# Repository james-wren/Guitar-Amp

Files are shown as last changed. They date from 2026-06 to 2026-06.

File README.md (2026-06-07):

# Guitar-Amp
## Description
A 4 inch and electric guitar amplifier using the LM386n-4 and J201 JFETS. Operates using 4 main stages:
1. JFET input boost, the signal coming from a guitar is very weak, so it needs to be boosted to a usable level
2. Tone control, uses a 50k POT to control the guitars tone, this stage decreases the signal strength
3. JFET tone boost, boosts the signal strength back up to usable level.
4. Audio amplification, uses the LM386n-4 to amplify the audio to ~1w, ideal for a 4 inch speaker



The board is designed to use only THT components to save money as it can ban easily soldered with basic tools, to aid in the easy assembly parts are also spread out over a almost 200mm width. Components start on the left with the 1/4 inch jack input, wrap around the top, and end on the right with the speaker output. It is mounted to the case using m2 screws.




The case is pretty simple, just a speaker on the front with the three potentiometers and input jack up top, the 12v barrel is located on the back of the case near the bottom, the case is printed in two parts, the back plate is printed seperatly and screwed on with two M2 screws.

  

Inside mounting holes of back plate:  



## Instructions
### Build 
1. Solder components onto the pcb, simply solder the through hole components, no special gear is needed.
2. Wire potentiometers, the input jack, 12v barrel, and the speaker. Solder using 22AWG wire to thier respective pads
3. Print case in any orientation prefered, note that supports will be needed for the main body.
4. Screw in components, the pcb and backplate use m2 screws, and the speaker uses m8.

### Usage
1. Plug in guitar, reccomend starting with this to avoid a loud, high piched noise.
2. Plug in 12v barrel to turn on amp
3. Adjust knobs to prefered tune
4. Play your guitar!

## Why I made this
Pretty simple, I don't have an AMP, but I do have a guitar (I actually built it myself). After building I decieded that I wanted to learn to play, until this I had been plugging it into my old ipod and using garage band as an amp, but this was pretty terrible so I decieded this would be a fun first hardware project

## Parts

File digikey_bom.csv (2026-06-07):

Country of Origin may be different at time of shipment.
The HTSUS and ECCN information shown is for informational purposes only and is not a representation or warranty as to the accuracy or reliability of these classifications. All information is provided "as is" and is subject to change without notice. Any use made of the information provided is without recourse to Digi-Key and at the user's risk.
Index | Manufacturer Part Number | Manufacturer Name | Description | Lead Time | Availability | Stock Status | Attrition % | Requested Quantity 1 | Pack Quantity 1 | Pack Type 1 | Digi-Key Part Number 1 | Unit Price 1 | Extended Price 1 | Minimum Order Quantity 1 | Customer Reference | Requested Part Number | Lead Weeks | Datasheet | Reference Designator | US Import Tariff | Note | Part Status | RoHS Status | REACH Status | Moisture Sensitivity Level (MSL) | ECCN | HTSUS | Country of Origin | Environmental Information | Original Part numbers | Unit of Measure | Image | Product Notes
1 | C315C682K5R5TA | KEMET | CAP CER 6800PF 50V X7R RADIAL |  | 7,642 | In Stock |  | 1 | 1 | Bulk | 399-4194-ND | 0.34000 | $0.34 | 1 |  | 399-4194-ND | 26 | https://yageogroup.com/content/datasheet/asset/file/KEM_C1050_GOLDMAX_X7R |  | - |  | Active | ROHS3 Compliant | REACH Unaffected | Not Applicable | EAR99 | 8532.24.0060 | Mexico |  | 399-4194-ND | Each | https://mm.digikey.com/Volume0/opasdata/d220001/medias/images/2503/GOLDENMAX%20300%20C0G%2C%20NP0.jpg
2 | A103K15X7RF5TAA | Vishay Beyschlag/Draloric/BC Components | CAP CER 10000PF 50V X7R AXIAL |  | 145,753 | In Stock |  | 1 | 1 | Cut Tape (CT) | 1103PHCT-ND | 0.26000 | $0.26 | 1 |  | 1103PHCT-ND | 18 | https://www.vishay.com/docs/45164/aseries.pdf |  | May apply on shipments to the U.S. |  | Active | ROHS3 Compliant | REACH Unaffected | Not Applicable | EAR99 | 8532.24.0040 | China |  | 1103PHCT-ND | Each | https://mm.digikey.com/Volume0/opasdata/d220001/medias/images/591/A152K15X7RF5TAA.jpg
3 | FK20X7S1H106KR000 | TDK | CAP CER 10UF 50V X7S RADIAL |  | 143,250 | In Stock |  | 2 | 2 | Bulk | 445-FK20X7S1H106K-ND | 1.24000 | $2.48 | 1 |  | 445-FK20X7S1H106K-ND | 40 | https://product.tdk.com/en/system/files/dam/doc/product/capacitor/ceramic/lead-mlcc/catalog/leadmlcc_conventional_fk_en.pdf |  | May apply on shipments to the U.S. |  | Not For New Designs | ROHS3 Compliant | REACH Unaffected | Not Applicable | EAR99 | 8532.24.0060 | China | https://product.tdk.com/en/environment/index.html | 445-FK20X7S1H106K-ND | Each | https://mm.digikey.com/Volume0/opasdata/d220001/medias/images/631/FK54-SERIES.jpg
4 | C410C104Z5U5TA7200 | KEMET | CAP CER 0.1UF 50V Z5U AXIAL |  | 165,394 | In Stock |  | 1 | 1 | Cut Tape (CT) | 399-C410C104Z5U5TA7200CT-ND | 0.26000 | $0.26 | 1 |  | 399-C410C104Z5U5TA7200CT-ND | 30 | https://yageogroup.com/content/datasheet/asset/file/KEM_C1042_AXIMAX_Z5U |  | May apply on shipments to the U.S. |  | Active | ROHS3 Compliant | REACH Unaffected | Not Applicable | EAR99 | 8532.24.0040 | Mexico |  | 399-C410C104Z5U5TA7200CT-ND | Each | https://mm.digikey.com/Volume0/opasdata/d220001/medias/images/1278/MFG_C4x0Cxxxxxx5TAAUTO.jpg
5 | UHE1H221MPD | Nichicon | CAP ALUM 220UF 20% 50V RADIAL TH |  | 64,731 | In Stock |  | 1 | 1 | Bulk | 493-1609-ND | 0.65000 | $0.65 | 1 |  | 493-1609-ND | 21 | https://www.nichicon.co.jp/english/series_items/catalog_pdf/e-uhe.pdf |  | - |  | Active | ROHS3 Compliant | REACH Affected | Not Applicable | EAR99 | 8532.22.0020 | Malaysia |  | 493-1609-ND | Each | https://mm.digikey.com/Volume0/opasdata/d220001/medias/images/2894/HE%20SERIES%20PURPLE%2016.0%2C10.0.jpg
6 | 50NXA100MEFC10X16 | Rubycon | CAP ALUM 100UF 20% 50V RADIAL TH |  | 2,213 | In Stock |  | 1 | 1 | Bulk | 1189-50NXA100MEFC10X16-ND | 0.82000 | $0.82 | 1 |  | 1189-50NXA100MEFC10X16-ND | 22 | https://www.rubycon.co.jp/wp-content/uploads/catalog-aluminum/NXA.pdf |  | May apply on shipments to the U.S. |  | Active | ROHS3 Compliant | REACH Unaffected | Not Applicable | EAR99 | 8532.22.0020 | Japan |  | 1189-50NXA100MEFC10X16-ND | Each | https://mm.digikey.com/Volume0/opasdata/d220001/medias/images/913/NXA-Series.jpg
7 | ECE-A1HN471U | Panasonic Industry | CAP ALUM 470UF 20% 50V RADIAL TH |  | 32 | In Stock |  | 1 | 1 | Bulk | P1287-ND | 2.72000 | $2.72 | 1 |  | P1287-ND | 31 | https://industrial.panasonic.com/cdbs/www-data/pdf/RDF0000/ABA0000C1053.pdf |  | May apply on shipments to the U.S. |  | Active | ROHS3 Compliant | REACH Unaffected | Not Applicable | EAR99 | 8532.22.0020 | Malaysia |  | P1287-ND | Each | https://mm.digikey.com/Volume0/opasdata/d220001/derivates/6/001/120/017/ECE-A1HN471U_web%28640x640%29.jpg
8 | 1N5338BRLG | onsemi | DIODE ZENER 5.1V 5W AXIAL |  | 23,668 | In Stock |  | 2 | 2 | Cut Tape (CT) | 1N5338BRLGOSCT-ND | 0.80000 | $1.60 | 1 |  | 1N5338BRLGOSCT-ND | 19 | https://www.onsemi.com/pub/Collateral/1N5333B-D.PDF |  | May apply on shipments to the U.S. |  | Active | ROHS3 Compliant | REACH Unaffected | Not Applicable | EAR99 | 8541.10.0050 | China | https://www.onsemi.com/site/pdf/RoHS-statement.pdf|https://www.onsemi.com/PowerSolutions/MaterialComposition.do?export=pdf&opnId=1N5338BRLG | 1N5338BRLGOSCT-ND | Each | https://mm.digikey.com/Volume0/opasdata/d220001/medias/images/5023/488%7E017AA-01%7E%7E2.jpg
9 | 1N4007 | Diotec Semiconductor | DIODE STANDARD 1000V 1A DO204AC |  | 42,464 | In Stock |  | 1 | 1 | Cut Tape (CT) | 4878-1N4007CT-ND | 0.14000 | $0.14 | 1 |  | 4878-1N4007CT-ND | 6 | https://diotec.com/request/datasheet/1n4001.pdf |  | May apply on shipments to the U.S. |  | Active | ROHS3 Compliant | REACH Unaffected | Not Applicable | EAR99 | 8541.10.0080 | China | https://diotec.com/request/imds/p1_e.pdf | 4878-1N4007CT-ND | Each | https://mm.digikey.com/Volume0/opasdata/d220001/derivates/6/003/243/002/MFG_4878%7EDO41-DO204AC%7E%7E2_web%28640x640%29.jpg
10 | EJ501A | MPD (Memory Protection Devices) | CONN PWR JACK 2.1X5.5MM SOLDER |  | 4,305 | In Stock |  | 1 | 1 | Bulk | EJ501A-ND | 1.89000 | $1.89 | 1 |  | EJ501A-ND | 20 | https://www.memoryprotectiondevices.com/datasheets/EJ501A/EJ501A-datasheet.pdf |  | May apply on shipments to the U.S. |  | Active | RoHS Compliant | REACH Unaffected | 1 (Unlimited) | EAR99 | 8536.69.4010 | Taiwan |  | EJ501A-ND | Each | https://mm.digikey.com/Volume0/opasdata/d220001/medias/images/1123/MFG_EJ501A.jpg
11 | CSS-1021028N | Same Sky (Formerly CUI Devices) | SPEAKER 8OHM 10W TOP PORT 107DB |  | 5,132 | In Stock |  | 1 | 1 | Box | 102-3849-ND | 7.92000 | $7.92 | 1 |  | 102-3849-ND | 18 | https://www.cuidevices.com/product/resource/css-1021028n.pdf |  | - |  | Active | ROHS3 Compliant | REACH Unaffected | Not Applicable | EAR99 | 8518.29.8000 | Taiwan | https://www.cuidevices.com/product/resource/material-compliance/css-1021028n | 102-3849-ND | Each | https://mm.digikey.com/Volume0/opasdata/d220001/medias/images/2196/MFG_CSS-1021028N.jpg
12 | J201 TO-92 3L ROHS | Linear Integrated Systems, Inc. | JFET N-CH 40V 10MA TO92 |  | 2,629 | In Stock |  | 2 | 2 | Bulk | 4004-J201TO-923LROHS-ND | 4.99000 | $9.98 | 1 |  | 4004-J201TO-923LROHS-ND | 8 | https://www.linearsystems.com/_files/ugd/7e8069_eac72fcda83f42c7942bbf15c07a36c7.pdf |  | - |  | Active | ROHS3 Compliant | REACH Unaffected | 1 (Unlimited) | EAR99 | 8541.21.0095 | United States |  | 4004-J201TO-923LROHS-ND | Each | https://mm.digikey.com/Volume0/opasdata/d220001/medias/images/6240/3218%7ETO92%7E%7E3.jpg | Non Cancellable Non Returnable.
13 | CF14JT1M00 | Stackpole Electronics Inc | RES 1M OHM 5% 1/4W AXIAL |  | 649,762 | In Stock |  | 2 | 2 | Cut Tape (CT) | CF14JT1M00CT-ND | 0.10000 | $0.20 | 1 |  | CF14JT1M00CT-ND | 18 | https://www.seielect.com/catalog/SEI-CF_CFM.pdf |  | May apply on shipments to the U.S. |  | Active | ROHS3 Compliant | REACH Unaffected | Not Applicable | EAR99 | 8533.10.0065 | China | https://www.seielect.com/catalog/SEI-RoHS_Compliance_Status.pdf|https://www.seielect.com/catalog/reach.pdf|https://www.seielect.com/catalog/sei-coc%20prop%2065.pdf | CF14JT1M00CT-ND | Each | https://mm.digikey.com/Volume0/opasdata/d220001/medias/images/2376/CF%201m.jpg
14 | CF12JT2K20 | Stackpole Electronics Inc | RES 2.2K OHM 5% 1/2W AXIAL |  | 53,500 | In Stock |  | 2 | 2 | Cut Tape (CT) | CF12JT2K20CT-ND | 0.10000 | $0.20 | 1 |  | CF12JT2K20CT-ND | 18 | https://www.seielect.com/catalog/SEI-CF_CFM.pdf |  | May apply on shipments to the U.S. |  | Active | ROHS3 Compliant | REACH Unaffected | Not Applicable | EAR99 | 8533.10.0065 | China | https://www.seielect.com/catalog/SEI-RoHS_Compliance_Status.pdf|https://www.seielect.com/catalog/reach.pdf|https://www.seielect.com/catalog/sei-coc%20prop%2065.pdf | CF12JT2K20CT-ND | Each | https://mm.digikey.com/Volume0/opasdata/d220001/medias/images/2440/CFSeries%202-2k.jpg
15 | CF12JT6K80 | Stackpole Electronics Inc | RES 6.8K OHM 5% 1/2W AXIAL |  | 48,288 | In Stock |  | 3 | 3 | Cut Tape (CT) | CF12JT6K80CT-ND | 0.10000 | $0.30 | 1 |  | CF12JT6K80CT-ND | 18 | https://www.seielect.com/catalog/SEI-CF_CFM.pdf |  | May apply on shipments to the U.S. |  | Active | ROHS3 Compliant | REACH Unaffected | Not Applicable | EAR99 | 8533.10.0065 | China | https://www.seielect.com/catalog/SEI-RoHS_Compliance_Status.pdf|https://www.seielect.com/catalog/reach.pdf|https://www.seielect.com/catalog/sei-coc%20prop%2065.pdf | CF12JT6K80CT-ND | Each | https://mm.digikey.com/Volume0/opasdata/d220001/medias/images/2440/CFSeries%206-8k.jpg
16 | CF12JT47K0 | Stackpole Electronics Inc | RES 47K OHM 5% 1/2W AXIAL |  | 242,403 | In Stock |  | 1 | 1 | Cut Tape (CT) | CF12JT47K0CT-ND | 0.10000 | $0.10 | 1 |  | CF12JT47K0CT-ND | 18 | https://www.seielect.com/catalog/SEI-CF_CFM.pdf |  | May apply on shipments to the U.S. |  | Active | ROHS3 Compliant | REACH Unaffected | Not Applicable | EAR99 | 8533.10.0065 | China | https://www.seielect.com/catalog/SEI-RoHS_Compliance_Status.pdf|https://www.seielect.com/catalog/reach.pdf|https://www.seielect.com/catalog/sei-coc%20prop%2065.pdf | CF12JT47K0CT-ND | Each | https://mm.digikey.com/Volume0/opasdata/d220001/medias/images/2376/CFSeries%2047k.jpg
17 | FW20A10R0JA | Bourns Inc. | RES 10 OHM 5% 2W AXIAL |  | 269 | In Stock |  | 1 | 1 | Cut Tape (CT) | FW20A10R0JACT-ND | 0.56000 | $0.56 | 1 |  | FW20A10R0JACT-ND | 19 | https://www.bourns.com/docs/Product-Datasheets/FW.pdf |  | May apply on shipments to the U.S. |  | Active | ROHS3 Compliant | REACH Unaffected | Not Applicable | EAR99 | 8533.21.0080 | China | https://mm.digikey.com/Volume0/opasdata/d220001/medias/docus/6657/Bourns%20REACH%20247%20Jan%202025%20Statement.pdf|https://www.bourns.com/docs/rohs-cofc/fw_coc.pdf?sfvrsn=257997f1_4 | FW20A10R0JACT-ND | Each | https://mm.digikey.com/Volume0/opasdata/d220001/medias/images/2500/FWxxA%2010.jpg
18 | PTN16-D50215K1B1 | Same Sky (Formerly CUI Devices) | POT 50K OHM 1/8W CARBON LINEAR |  | 463 | In Stock |  | 2 | 2 | Tray | 2223-PTN16-D50215K1B1-ND | 1.20000 | $2.40 | 1 |  | 2223-PTN16-D50215K1B1-ND | 15 | https://mm.digikey.com/Volume0/opasdata/d220001/medias/docus/7159/all-you-need-to-know-about-potentiometers.pdf |  | May apply on shipments to the U.S. |  | Active | ROHS3 Compliant | REACH Unaffected | Not Applicable | EAR99 | 8533.40.8070 | China | https://mm.digikey.com/Volume0/opasdata/d220001/medias/common/5783/ptn16-d50215k1b1.html | 2223-PTN16-D50215K1B1-ND | Each | https://mm.digikey.com/Volume0/opasdata/d220001/derivates/6/001/168/953/PTN16-D50215K1B1_web%28640x640%29.jpg
19 | PDB181-E420K-503A2 | Bourns Inc. | POT 50K OHM 1/10W CARBON LOG |  | 657 | In Stock |  | 1 | 1 | Tray | 118-PDB181-E420K-503A2-ND | 1.77000 | $1.77 | 1 |  | 118-PDB181-E420K-503A2-ND | 23 | https://www.bourns.com/docs/Product-Datasheets/PDB18.pdf |  | May apply on shipments to the U.S. |  | Active | ROHS3 Compliant | REACH Unaffected | Not Applicable | EAR99 | 8533.40.8070 | China | https://mm.digikey.com/Volume0/opasdata/d220001/medias/docus/6657/Bourns%20REACH%20247%20Jan%202025%20Statement.pdf|https://www.bourns.com/docs/rohs-cofc/pc1_coc.pdf?sfvrsn=cf7e2294_6 | 118-PDB181-E420K-503A2-ND | Each | https://mm.digikey.com/Volume0/opasdata/d220001/derivates/6/003/234/789/PDB181-E420K-503A2_web%28640x640%29.jpg
20 | L7809CV | UMW | IC REG LINEAR 9V 1.2A TO220 |  | 1,155 | In Stock |  | 1 | 1 | Tube | 4518-L7809CV-ND | 0.42000 | $0.42 | 1 |  | 4518-L7809CV-ND | 8 | https://www.umw-ic.com/static/pdf/5a38e4cbf2cd3bf774fcded71c6288c1.pdf |  | - |  | Active | ROHS3 Compliant | REACH Unaffected | 1 (Unlimited) | EAR99 | 8542.39.0090 | China |  | 4518-L7809CV-ND | Each | https://mm.digikey.com/Volume0/opasdata/d220001/derivates/6/003/215/772/MFG_4518_TO-220_web%28640x640%29.jpg
21 | LM386N-4/NOPB | Texas Instruments | IC AMP CLASS AB MONO 1W 8DIP |  | 8,259 | In Stock |  | 1 | 1 | Tube | 296-43960-5-ND | 1.18000 | $1.18 | 1 |  | 296-43960-5-ND | 18 | https://www.ti.com/general/docs/suppproductinfo.tsp?distId=10 |  | May apply on shipments to the U.S. |  | Active | ROHS3 Compliant | REACH Unaffected | 1 (Unlimited) | EAR99 | 8542.33.0001 | Germany |  | 296-43960-5-ND | Each | https://mm.digikey.com/Volume0/opasdata/d220001/medias/images/6222/296%7E4040082%7EP%7E8.jpg
22 | 11 | Switchcraft Inc. | CONN JACK MONO 6.35MM PNL MNT |  | 7,339 | In Stock |  | 1 | 1 | Bulk | SC1085-ND | 4.09000 | $4.09 | 1 |  | SC1085-ND | 10 | https://www.switchcraft.com/assets/1/24/11_cd.pdf?5172 |  | - |  | Active | ROHS3 Compliant | REACH Unaffected | Not Applicable | EAR99 | 8536.69.4020 | United States | https://www.switchcraft.com/assets/1/6/RoHS_2015_863_EU_CoC_Switchcraft_General_Statement.pdf | SC1085-ND | Each | https://mm.digikey.com/Volume0/opasdata/d220001/medias/images/402/11.jpg
23 | K473K15X7RF53L2 | Vishay Beyschlag/Draloric/BC Components | CAP CER 0.047UF 50V X7R RADIAL |  | 149,758 | In Stock |  | 3 | 3 | Bulk | BC5153-ND | 0.27000 | $0.81 | 1 |  | BC5153-ND | 18 | https://www.vishay.com/docs/45171/kseries.pdf |  | May apply on shipments to the U.S. |  | Active | ROHS3 Compliant | REACH Unaffected | Not Applicable | EAR99 | 8532.24.0060 | China |  | BC5153-ND | Each | https://mm.digikey.com/Volume0/opasdata/d220001/medias/images/4847/56_K102K15X7RF5TL2.jpg
24 | RNMF14FTC22K0 | Stackpole Electronics Inc | RES 22K OHM 1% 1/4W AXIAL |  | 79,646 | In Stock |  | 1 | 1 | Cut Tape (CT) | S22KCACT-ND | 0.10000 | $0.10 | 1 |  | S22KCACT-ND | 18 | https://www.seielect.com/catalog/SEI-RNF_RNMF.pdf |  | May apply on shipments to the U.S. |  | Active | ROHS3 Compliant | REACH Unaffected | Not Applicable | EAR99 | 8533.21.0090 | China | https://www.seielect.com/catalog/SEI-RoHS_Compliance_Status.pdf|https://www.seielect.com/catalog/reach.pdf|https://www.seielect.com/catalog/sei-coc%20prop%2065.pdf | S22KCACT-ND | Each | https://mm.digikey.com/Volume0/opasdata/d220001/medias/images/2586/RNMF14%2022k.jpg

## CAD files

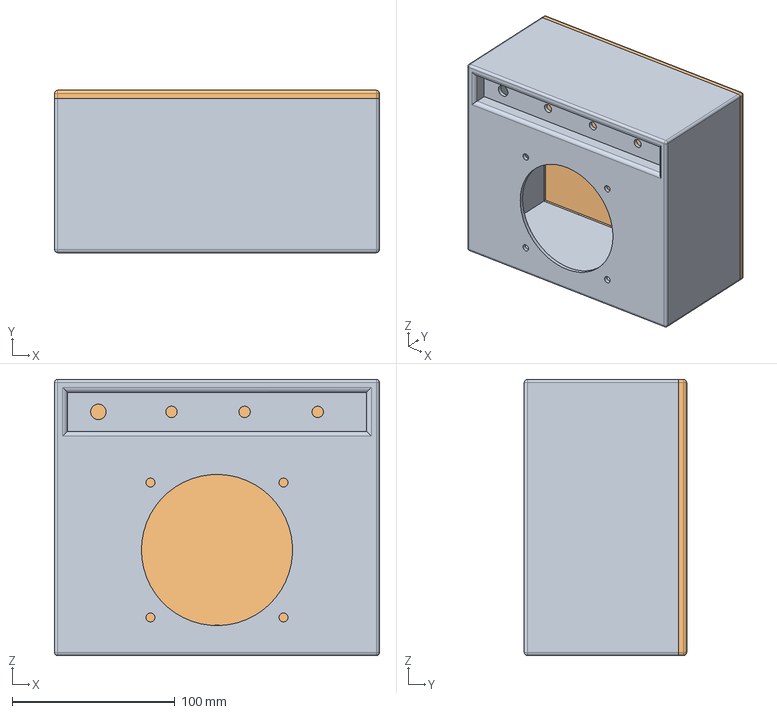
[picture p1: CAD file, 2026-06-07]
case/Amp Case.step
200.0 x 100.0 x 170.0 mm

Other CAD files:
case/Amp Case.3mf
case/Amp Case.f3d

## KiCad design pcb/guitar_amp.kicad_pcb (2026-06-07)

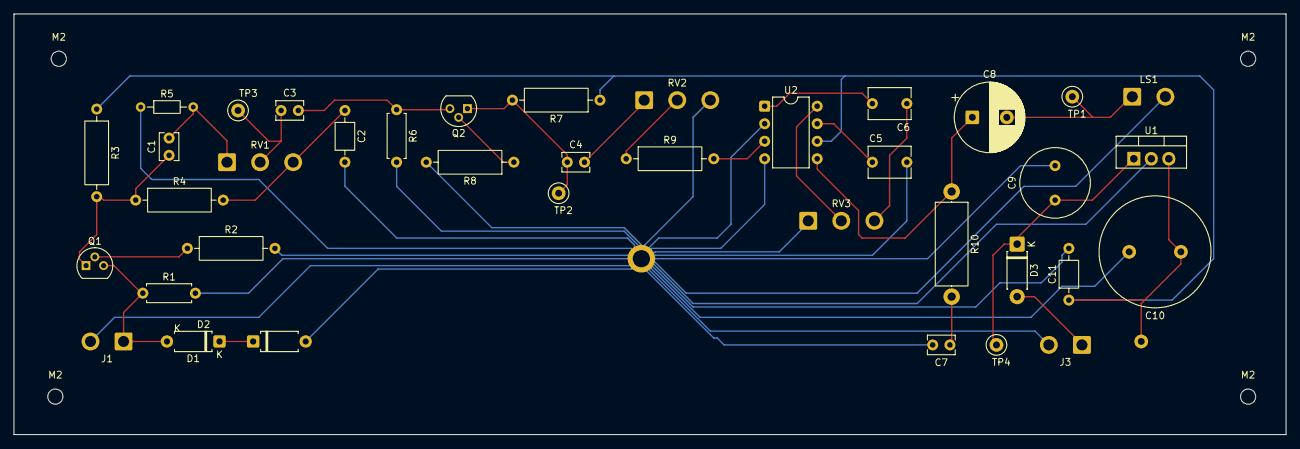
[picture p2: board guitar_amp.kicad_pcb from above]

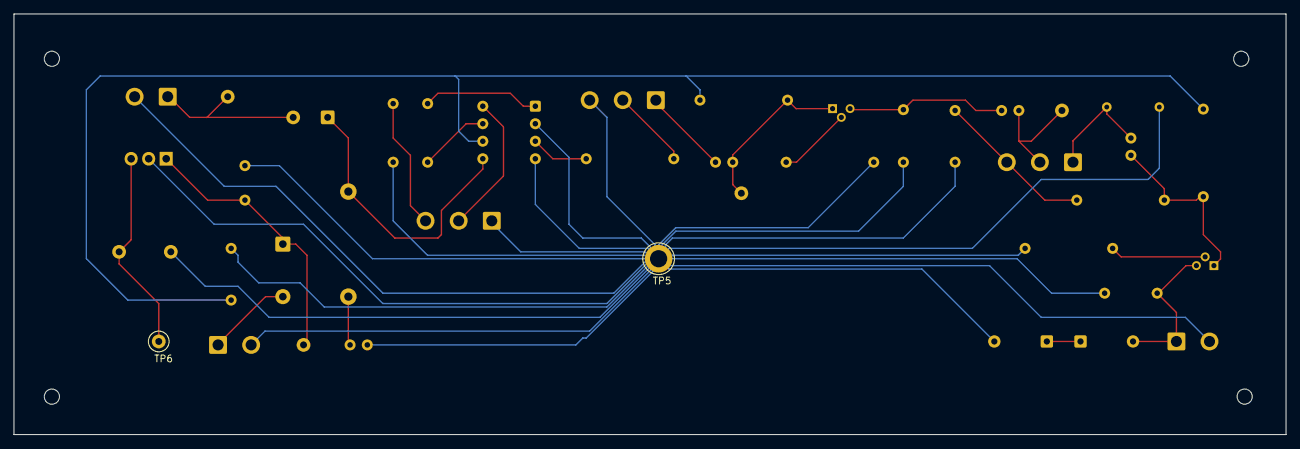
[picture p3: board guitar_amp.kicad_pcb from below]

Board: 2 copper layers, 184.5 x 61.0 mm, 44 parts (2 on the bottom side), 24 nets.

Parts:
C1: 6.8N; C_Disc_D3.8mm_W2.6mm_P2.50mm
C2: 10n; C_Axial_L3.8mm_D2.6mm_P7.50mm_Horizontal
C3, C4, C7: 47n; C_Disc_D3.8mm_W2.6mm_P2.50mm
C5, C6: 10uF; C_Disc_D6.0mm_W4.4mm_P5.00mm
C8: 220uF; CP_Radial_D10.0mm_P5.00mm
C9: 100uF; C_Radial_D10.0mm_H16.0mm_P5.00mm
C10: 470uF; C_Radial_D16.0mm_H31.5mm_P7.50mm
C11: 100nF; C_Axial_L3.8mm_D2.6mm_P7.50mm_Horizontal
D1, D2: 5.1v; D_A-405_P7.62mm_Horizontal
D3: 1N4007; D_DO-41_SOD81_P7.62mm_Horizontal
J1: 6.35mm Mono Jack; SolderWire-0.75sqmm_1x02_P4.8mm_D1.25mm_OD2.3mm
J3: Conn_Coaxial; SolderWire-0.75sqmm_1x02_P4.8mm_D1.25mm_OD2.3mm
LS1: 5 inch speaker; SolderWire-0.75sqmm_1x02_P4.8mm_D1.25mm_OD2.3mm
M2, M2#2, M2#3, M2#4: MountingHole_2.2mm_M2
Q1, Q2: J201; TO-92
R1, R6: 1M; R_Axial_DIN0207_L6.3mm_D2.5mm_P7.62mm_Horizontal
R2, R8: 2K2; R_Axial_DIN0309_L9.0mm_D3.2mm_P12.70mm_Horizontal
R3, R7, R9: 6K8; R_Axial_DIN0309_L9.0mm_D3.2mm_P12.70mm_Horizontal
R4: 47K; R_Axial_DIN0309_L9.0mm_D3.2mm_P12.70mm_Horizontal
R5: 22K; R_Axial_DIN0204_L3.6mm_D1.6mm_P7.62mm_Horizontal
R10: 10R; R_Axial_DIN0414_L11.9mm_D4.5mm_P15.24mm_Horizontal
RV1, RV3: 50K; SolderWire-0.75sqmm_1x03_P4.8mm_D1.25mm_OD2.3mm
RV2: A50K; SolderWire-0.75sqmm_1x03_P4.8mm_D1.25mm_OD2.3mm
TP1: Speaker; TestPoint_Loop_D2.50mm_Drill1.0mm
TP2: Boost; TestPoint_Loop_D2.50mm_Drill1.0mm
TP3: Tone; TestPoint_Loop_D2.50mm_Drill1.0mm
TP4: 12v Raw; TestPoint_Loop_D2.50mm_Drill1.0mm
TP5: GND Ref; TestPoint_Loop_D3.80mm_Drill2.5mm
TP6: 9v; TestPoint_Loop_D2.50mm_Drill1.0mm
U1: L7809; TO-220-3_Vertical
U2: LM386n-4; DIP-8_W7.62mm

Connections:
BOOST_OUT: C4.1, Q2.1 (D), R7.2, TP2.1 (1_1)
GND: C2.2, C5.2, C7.2, C9.2, C10.2, C11.2, D2.2 (A), J1.2, J3.2 (Ext), LS1.2, R1.2, R2.2, R5.1, R6.2, R8.2, RV2.3, RV3.1, TP5.1 (1_1), U1.2 (GND), U2.2 (-), U2.4 (GND)
INPUT_OUT: C1.1, Q1.1 (D), R3.2, R4.1
unnamed: C1.2, R5.2, RV1.1
unnamed: C2.1, R4.2, RV1.3
unnamed: C4.2, RV2.1
unnamed: C6.1, RV3.3
unnamed: C6.2, U2.1 (GAIN)
unnamed: C7.1, R10.2
unnamed: C8.1, R10.1, U2.5
unnamed: C8.2, LS1.1, TP1.1 (1_1)
unnamed: D1.2 (A), J1.1, Q1.3 (G), R1.1
unnamed: D1.1 (K), D2.1 (K)
unnamed: D3.2 (A), J3.1 (In)
unnamed: C9.1, D3.1 (K), TP4.1 (1_1), U1.1 (IN)
unnamed: Q1.2 (S), R2.1
unnamed: C3.2, Q2.3 (G), R6.1
unnamed: Q2.2 (S), R8.1
unnamed: R9.1, RV2.2
unnamed: RV3.2, U2.8 (GAIN)
unnamed: R9.2, U2.3 (+)
unnamed: C5.1, U2.7 (BYPASS)
TONE_OUT: C3.1, RV1.2, TP3.1 (1_1)
VCC: C10.1, C11.1, R3.1, R7.1, TP6.1 (1_1), U1.3 (OUT), U2.6 (V+)

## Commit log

2026-06-07 Create case dir
2026-06-07 Create pcb dir
2026-06-07 Added 3d files
    [Amp Case.3mf, Amp Case.f3d, Amp Case.step]
2026-06-07 Added pcb files
    [guitar_amp.kicad_pcb, guitar_amp.kicad_sch]
2026-06-07 Added digikey BOM
    [Guitar amp.csv]
2026-06-07 Rename Guitar amp.csv to digikey_bom.csv
    [digikey_bom.csv]
